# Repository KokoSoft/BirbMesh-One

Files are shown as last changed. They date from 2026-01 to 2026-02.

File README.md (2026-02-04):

# BirbMesh-One :bird:

The goal of **Birb**s **Mesh**tastic **One** Watt node project was to create an inexpensive and as small as possible Meshtastic node equipped with a 1 W radio module. An important aspect, from my perspective, is ensuring favorable operating conditions for the battery to extend its lifespan. The project supports multiple configuration variants, and the final functionality depends on the components you choose to solder. The core of the design is the energy‑efficient *nRF52840* controller mounted on a ProMicro board. The project is pin‑compatible with [xiaoWa_pcb](https://github.com/gargomoma/xiaoWa_pcb) and [FakeTec](https://github.com/gargomoma/fakeTec_pcb), which means no custom firmware is required.

**Key features**:
- Compact PCB: 27 × 47 mm
- Support for radio modules: E22(M), Ra‑01SH‑P, HT‑RA62
- Optional LCD and user button support
- Optional battery charging control (hardware or software)
- Optional battery voltage monitoring

## Project Description

The project was inspired by the [ikona nano](https://github.com/ndoo/ikoka-nano-meshtastic-device) and [xiaoWa_pcb](https://github.com/gargomoma/xiaoWa_pcb). The former is based on the Seeed Studio XIAO BLE, which is significantly more expensive than the ProMicro and offers fewer available GPIO pins. Additionally, the board is large and includes connectors for the battery and solar panel, which I found unnecessary. A notable strength is the correct implementation of the power supply for the boost converter that generates the supply voltage for the radio module. Another benefit, in my opinion, is the integration of the converter directly on the PCB, which allows it to be controlled programmatically. This makes it possible to switch it off to save energy. It is a project worth recommending, and using the XIAO BLE may be a good choice for those who prefer not to rely on low‑quality ProMicro boards.

Initially, this project was created as an attempt to solve the power‑supply issue present in xiaoWa_pcb, which requires a connected battery for proper operation. The boost converter powering the radio module draws energy directly from the battery connector. Without a battery, the system is powered solely by the *TP4054* charger IC, which has current limiting and built‑in protections. Although the charging current is configurable, it may be reduced to 1/10 of the set value under certain conditions, making it impossible to use the board with external power only. Using the inexpensive *HW‑085* boost converter module is an interesting idea and certainly simplifies building the device. Unfortunately, it cannot be switched off to save power.

<details>
<summary>Notes from the TP4054 datasheet</summary>

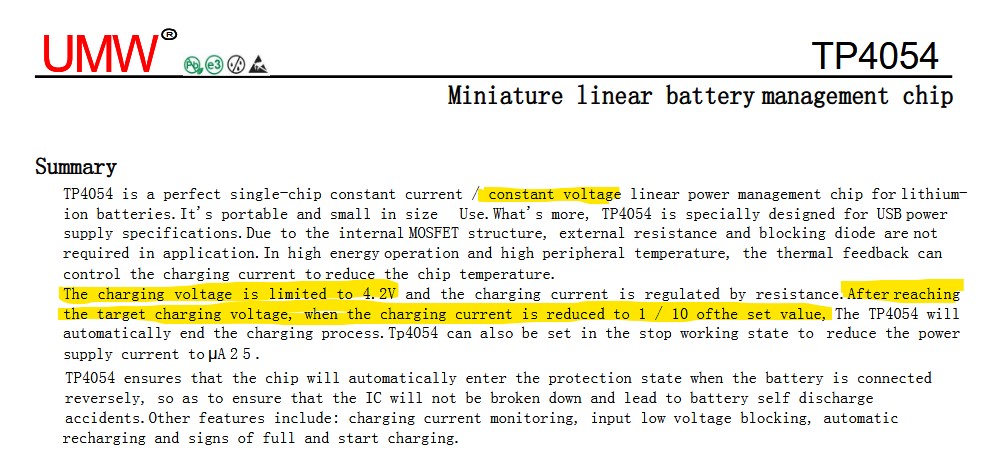
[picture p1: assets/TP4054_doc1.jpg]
TP4054 summary


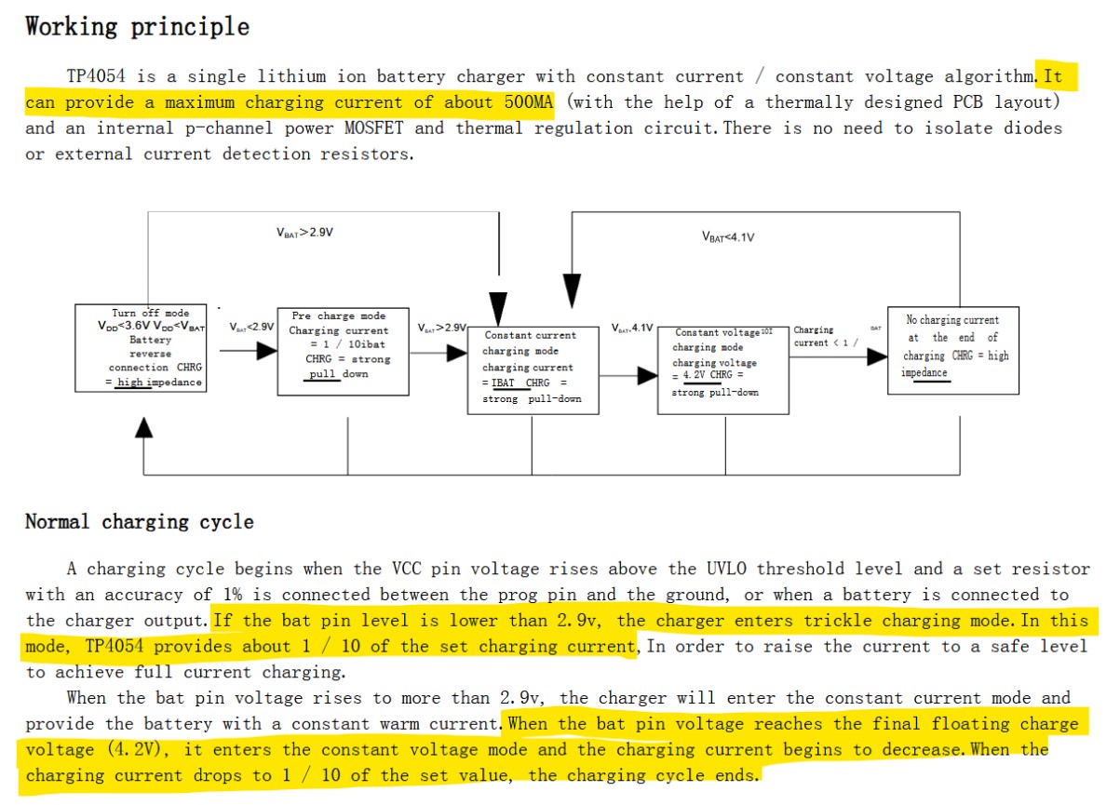
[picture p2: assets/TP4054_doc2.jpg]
TP4054 working principle


</details>

### Power Supply

There are three possible ways to power the radio module:

#### 1. Power from the ProMicro

To properly power the radio module and minimize energy loss, power must be taken from the switching circuit that selects power between USB voltage (*VBUS*) and battery voltage (*VBAT*). On the schematic, this point is labeled **VDDH**. This ensures that neither the battery nor the charger IC is loaded when device is powered from USB. You must route wire from the indicated point on the ProMicro board to the VDDH pad.

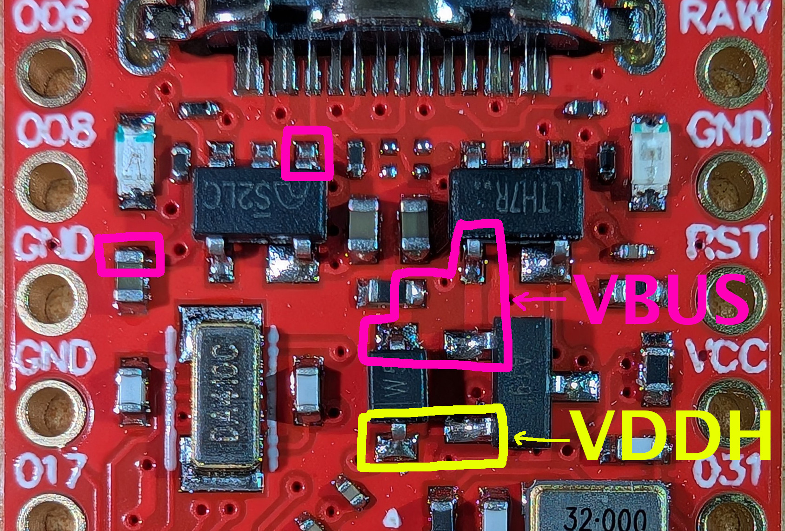
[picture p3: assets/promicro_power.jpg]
ProMicro power pads

<sub>Image created using a photo from the [nrf52840‑promicro](https://github.com/sasodoma/nrf52840-promicro) repository by [sasodoma](https://github.com/sasodoma).

Optionally, if you want to supply 5 V externally (through connector `J1`) without using USB socket, connect the VBUS pad as well.

#### 2. Independent power‑switching circuit

If you prefer not to draw high current through the questionable‑quality components on the ProMicro, you can build your own voltage‑switching circuit. To do this, solder components `Q1` and `D1`. You must also connect the VBUS pad to allow powering the radio from USB.

#### 3. Compatibility mode with xiaoWa_pcb

If you want to minimize soldering and always use the device with battery connected, you can use this compatibility mode. Short the `JP1` jumper on the bottom of the PCB. The radio will be powered directly from the battery, which will load the charger IC too.

### Boost Converter

High‑power radio modules require a 5 V supply to operate at full output power. This voltage is provided by a boost converter. If you are ordering an assembled board or are comfortable with soldering, the best solution is to build the converter using the *MT3608* IC. Populate components `L1`, `U4`, `D3`, `R11`, `R12`, `C7`, and `C9`.

Alternatively, to avoid soldering small components, you may use the *HW‑085* boost module. In its default configuration, it cannot be disabled to reduce power consumption. However, the project allows adding power control: cut jumper `JP7` (shorted by default) and solder `Q3`, `Q4`, and `R13`.

> [!NOTE]
> If you plan to use a radio module that does not require 5 V (e.g., *HT‑RA62*) or do not need full transmit power, you may omit the boost converter.

### Radio Module

Based on my experience with Meshtastic networks, using an 868 MHz SAW filter significantly improves reception quality, though they have low power tolerance. Cavity filters, on the other hand, are large and expensive. In Europe, the *E22P‑868M30S* module appears to be an ideal solution, offering a built‑in receive‑path filter and high transmit power.

#### E22 / E22P Module

The module supports a wide supply range of 3.3 -- 5 V. Full transmit power requires ≥5 V, so a boost converter is necessary. If full power is not required, you may omit the converter and short *VIN* to *VOUT*. The supply voltage will then equal the battery voltage or approximately 4.7 V when externally powered.

The *T/R CTRL* (*RXEN*) pin is controlled by *SX126x* *DIO2*. The *EN* (*TXEN*) pin is controlled by nRF `P0.17`.

#### Ra‑01SH‑P Module

This module is a cheaper alternative to the E22 series, offering 29/31 dBm output power. However, **it does not include a TCXO**. To achieve full power, 5 V must be supplied to the *VCCPA* pin, requiring a boost converter and shorting pads 1–2 on `JP6`.

> [!IMPORTANT]
> The modules documentation states: _"In the default BOM configuration of the Ra‑01SH‑P module, PA is powered by the 3V3 pin of the module, and the VCCPA pin can be left floating."_

#### HT‑RA62 Module

This module is powered from the ProMicro **EXTVCC** 3.3 V rail. No boost converter is required. Short pads 2–3 on `JP6` to connect *DIO2* to *TXEN*.

### Battery Voltage Monitoring (optional)

The monitoring circuit uses two comparators with hysteresis. U1 (*MIC841H*) asserts reset when battery voltage drops below 3.6 V (\~20% charge). Reset is released above 3.7 V (\~30%).

`U2` limits the maximum charge level. When voltage exceeds 4.05 V (\~80%), the `PROG` pin of the *TP4054* charger is disconnected.

To enable charge control, remove the charging‑current‑setting resistor from the ProMicro.
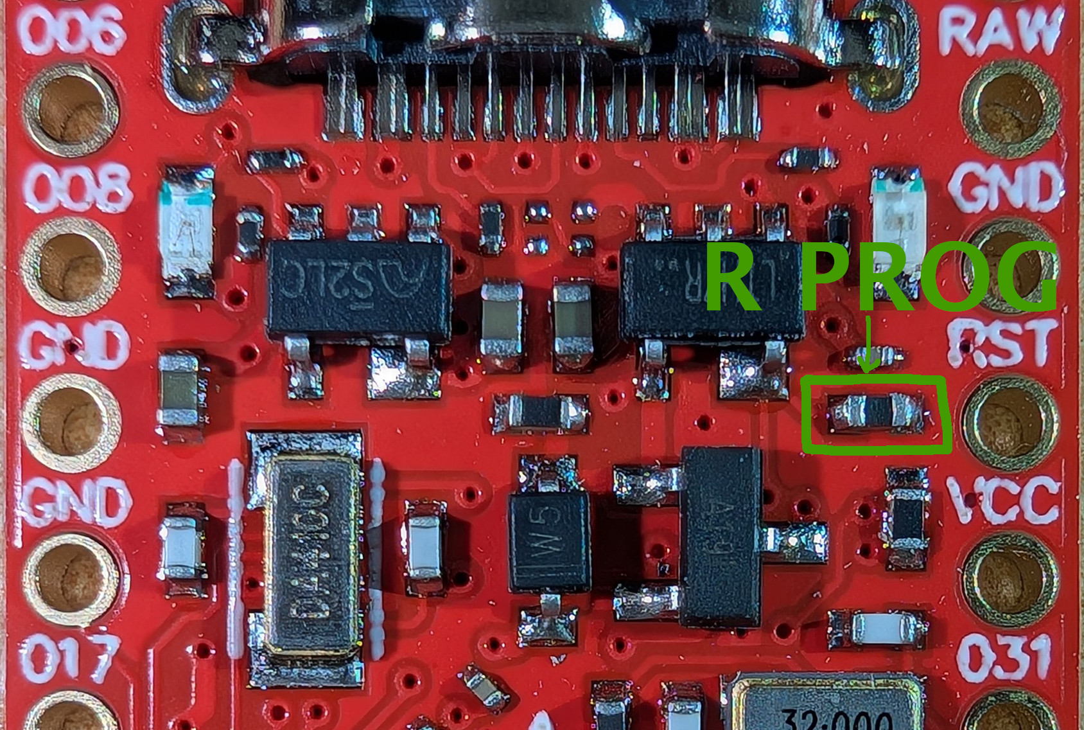
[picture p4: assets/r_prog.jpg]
Charging‑current‑setting resistor on ProMicro

<sub>Image created using a photo from the [nrf52840‑promicro](https://github.com/sasodoma/nrf52840-promicro) repository by [sasodoma](https://github.com/sasodoma).

Charging current is set by resistor `R8`.

Comparator thresholds are configured using the resistor divider `R2–R5`. Capacitor `C1` filters voltage fluctuations during radio transmission to prevent unwanted resets.

If you do not want hardware‑level reset and charge control but still want battery‑level monitoring in software, install only `R1` and `R2`.

#### Charge Control

To control charging from firmware:

- Remove the charging‑current‑setting resistor from the ProMicro.
- Install `R8` to set the desired charging current.
- Short `JP5` or install `Q2`.

## Ordering the PCBs
## Preparing firmware
## Soldering

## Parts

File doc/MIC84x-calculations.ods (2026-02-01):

Voltage calculations:
R1 | 1966 | VREF | 1,24 | V | Internal reference voltage
R2 | 28 | VIN(LO) | 3,599961278 | V | Power off
R3 | 87 | VIN(HI) | 3,700258706 | V | Power on
R4 | 918 | VIN2(LO) | 4,050936819 | V | Disable charger
S | 2999
Resistors calulation:
R1 | 1966,666667
R2 | 27,92792793 | VIN(LO) | 3,6 | V | Power off
R3 | 86,88688689 | VIN(HI) | 3,7 | V | Power on
R4 | 918,5185185 | VIN2(LO) | 4,05 | V | Disable charger
Target: | 3000

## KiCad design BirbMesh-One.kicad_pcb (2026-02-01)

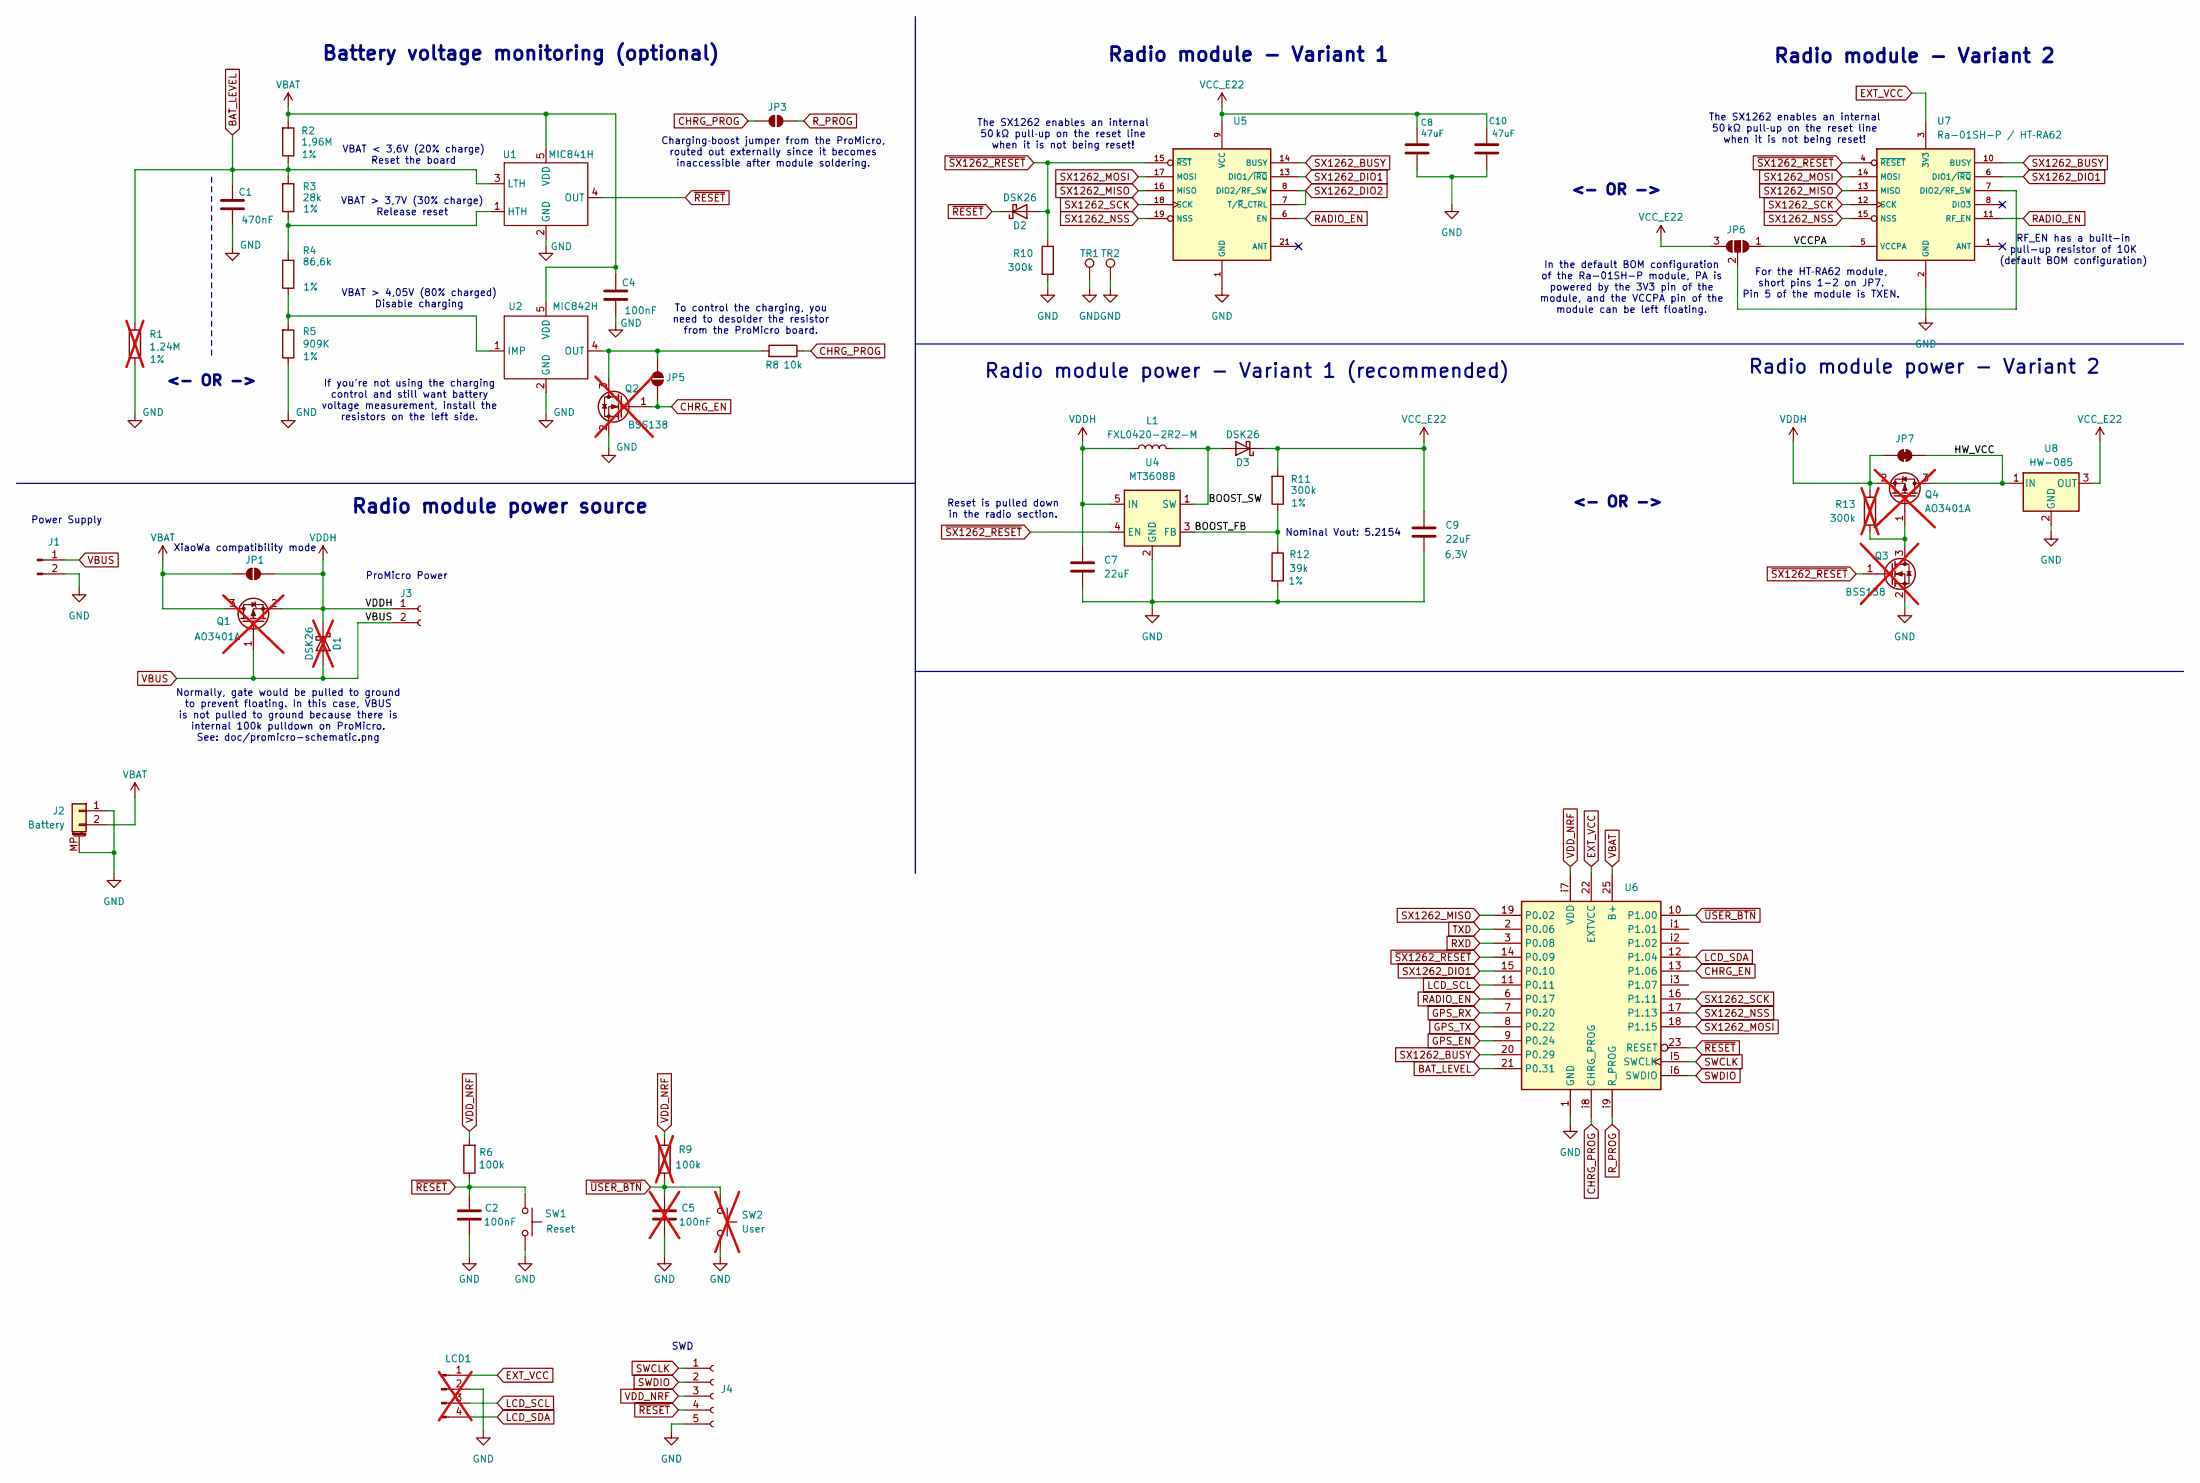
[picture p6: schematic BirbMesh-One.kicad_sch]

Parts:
C1: 470nF; C_0603_1608Metric_Pad1.08x0.95mm_HandSolder; Voltage 6,3V
C2: 100nF; C_0603_1608Metric_Pad1.08x0.95mm_HandSolder
C4: 100nF; C_0603_1608Metric_Pad1.08x0.95mm_HandSolder; Voltage 6,3V
C5: 100nF; C_0603_1608Metric_Pad1.08x0.95mm_HandSolder; not fitted
C7: 22uF; C_0603_1608Metric_Pad1.08x0.95mm_HandSolder; MPN CL10A226MQ8NRNC; LCSC C59461
C8, C10: 47uF; C_0805_2012Metric_Pad1.18x1.45mm_HandSolder; MPN CL31A107MQHNNNE; LCSC C15008
C9: 22uF; C_0603_1608Metric_Pad1.08x0.95mm_HandSolder; Voltage 6,3V; MPN CL10A226MQ8NRNC; LCSC C59461
D1: DSK26; D_SOD-123F; LCSC C7502712; not fitted
D2, D3: DSK26; D_SOD-123F; LCSC C7502712
J1: Conn_01x04_Pin; PinHeader_1x02_P2.54mm_Vertical
J2: Battery; JST_PH_S2B-PH-SM4-TB_1x02-1MP_P2.00mm_Horizontal
J3: Conn_01x02_Socket; PinHeader_1x02_P2.54mm_Vertical
J4: Conn_01x05_Socket; PinHeader_1x05_P1.27mm_Vertical
JP1, JP3, JP5: SolderJumper_2_Open; SolderJumper-2_P1.3mm_Open_TrianglePad1.0x1.5mm
JP6: SolderJumper_3_Open; SolderJumper-3_P1.3mm_Open_RoundedPad1.0x1.5mm
JP7: SolderJumper_2_Bridged; SolderJumper-2_P1.3mm_Bridged_Pad1.0x1.5mm
L1: FXL0420-2R2-M; L_Changjiang_FXL0420; MPN SMMS0650-220M; LCSC C167860
LCD1: Conn_01x04_Pin; PinHeader_1x04_P2.54mm_Vertical; not fitted
Q1, Q4: AO3401A; SOT-23; LCSC C15127; not fitted
Q2, Q3: BSS138; SOT-23; not fitted
R1: 1,24M; R_0603_1608Metric_Pad0.98x0.95mm_HandSolder; Tolerance 1%; not fitted
R2: 1,96M; R_0603_1608Metric_Pad0.98x0.95mm_HandSolder; Tolerance 1%
R3: 28k; R_0603_1608Metric_Pad0.98x0.95mm_HandSolder; Tolerance 1%
R4: 86,6k; R_0603_1608Metric_Pad0.98x0.95mm_HandSolder; Tolerance 1%
R5: 909K; R_0603_1608Metric_Pad0.98x0.95mm_HandSolder; Tolerance 1%
R6: 100k; R_0603_1608Metric_Pad0.98x0.95mm_HandSolder
R8: 10k; R_0603_1608Metric_Pad0.98x0.95mm_HandSolder
R9: 100k; R_0603_1608Metric_Pad0.98x0.95mm_HandSolder; not fitted
R10: 300k; R_0603_1608Metric_Pad0.98x0.95mm_HandSolder; MPN 0603WAF1502T5E
R11: 300k; R_0603_1608Metric_Pad0.98x0.95mm_HandSolder; Tolerance 1%
R12: 39k; R_0603_1608Metric_Pad0.98x0.95mm_HandSolder; Tolerance 1%; LCSC C22843
R13: 300k; R_0603_1608Metric_Pad0.98x0.95mm_HandSolder; MPN 0603WAF1502T5E; not fitted
SW1: Reset; SW_Push_SPST_NO_Alps_SKRK
SW2: User; SW_Push_SPST_NO_Alps_SKRK; LCSC C318884; not fitted
TR1, TR2: PTH; PinSocket_1x01_P2.54mm_Vertical
U1: MIC841H; SOT-353_SC-70-5
U2: MIC842H; SOT-353_SC-70-5
U4: MT3608B; SOT-23-6; LCSC C2932326
U5: E22P-868M30S
U6: ProMicro-all-pins_smd
U7: Ra-01SH-P / HT‑RA62; Ra-01SH-P
U8: HW-085

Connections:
/BOOST_FB: R11.1, R12.1, U4.3 (FB)
/BOOST_SW: D3.2 (A), L1.2, U4.1 (SW)
/HW_VCC: JP7.2 (B), Q4.3 (D), U8.1 (IN)
/VCCPA: JP6.1 (A), U7.5 (VCCPA)
BAT_LEVEL: C1.1, R1.2, R2.1, R3.2, U1.3 (LTH), U6.21 (P0.31)
CHRG_EN: JP5.1 (A), Q2.1 (G), U6.13 (P1.06)
CHRG_PROG: JP3.1 (A), R8.1, U6.i8 (CHRG_PROG)
EXT_VCC: LCD1.1, U6.22 (EXTVCC), U7.3 (3V3)
GND: C1.2, C2.1, C4.2, C5.1, C7.2, C8.1, C9.2, C10.1, J1.2, J2.1, J2.MP (MountPin), J4.5, LCD1.2, Q2.2 (S), Q3.2 (S), R1.1, R5.1, R10.2, R12.2, SW1.1, SW2.2, TR1.1, TR2.1, U1.2 (GND), U2.2 (GND), U4.2 (GND), U5.1 (GND), U6.1 (GND), U7.2 (GND), U8.2 (GND)
GPS_EN: U6.9 (P0.24)
GPS_RX: U6.7 (P0.20)
GPS_TX: U6.8 (P0.22)
LCD_SCL: LCD1.3, U6.11 (P0.11)
LCD_SDA: LCD1.4, U6.12 (P1.04)
unnamed: JP5.2 (B), Q2.3 (D), R8.2, U2.4 (OUT)
unnamed: JP6.2 (C), U7.7 (DIO2/RF_SW)
unnamed: Q3.3 (D), Q4.1 (G), R13.2
unnamed: R3.1, R4.2, U1.1 (HTH)
unnamed: R4.1, R5.2, U2.1 (IMP)
RADIO_EN: U5.6 (EN), U6.6 (P0.17), U7.11 (RF_EN)
RXD: U6.3 (P0.08)
R_PROG: JP3.2 (B), U6.i9 (R_PROG)
SWCLK: J4.1, U6.i5 (SWCLK)
SWDIO: J4.2, U6.i6 (SWDIO)
SX1262_BUSY: U5.14 (BUSY), U6.20 (P0.29), U7.10 (BUSY)
SX1262_DIO1: U5.13 (DIO1/~IRQ), U6.15 (P0.10), U7.6 (DIO1/~IRQ)
SX1262_DIO2: U5.7 (T/~R_CTRL), U5.8 (DIO2/RF_SW)
SX1262_MISO: U5.16 (MISO), U6.19 (P0.02), U7.13 (MISO)
SX1262_MOSI: U5.17 (MOSI), U6.18 (P1.15), U7.14 (MOSI)
SX1262_NSS: U5.19 (NSS), U6.17 (P1.13), U7.15 (NSS)
SX1262_SCK: U5.18 (SCK), U6.16 (P1.11), U7.12 (SCK)
TXD: U6.2 (P0.06)
VBAT: C4.1, J2.2, JP1.1 (A), Q1.3 (D), R2.2, U1.5 (VDD), U2.5 (VDD), U6.25 (B+)
VBUS: D1.2 (A), J1.1, J3.2, Q1.1 (G)
VCC_E22: C8.2, C9.1, C10.2, D3.1 (K), JP6.3 (B), R11.2, U5.9 (VCC), U8.3 (OUT)
VDDH: C7.1, D1.1 (K), J3.1, JP1.2 (B), JP7.1 (A), L1.1, Q1.2 (S), Q4.2 (S), R13.1, U4.5 (IN)
VDD_NRF: J4.3, R6.2, R9.2, U6.i7 (VDD)
~RESET: C2.2, D2.1 (K), J4.4, R6.1, SW1.2, U1.4 (OUT), U6.23 (RESET)
~SX1262_RESET: D2.2 (A), Q3.1 (G), R10.1, U4.4 (EN), U5.15 (~RST), U6.14 (P0.09), U7.4 (~RESET)
~USER_BTN: C5.2, R9.1, SW2.1, U6.10 (P1.00)

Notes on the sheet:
Radio module - Variant 2
For the HT‑RA62 module, short pins 1-2 on JP7. Pin 5 of the module is TXEN.
To control the charging, you need to desolder the resistor from the ProMicro board.
The SX1262 enables an internal 50 kΩ pull‑up on the reset line when it is not being reset!
SWD
VBAT > 4,05V (80% charged) Disable charging
Radio module power - Variant 1 (recommended)
Radio module - Variant 1
<- OR ->
VBAT > 3,7V (30% charge) Release reset
Radio module power source
Battery voltage monitoring (optional)
Radio module power - Variant 2
XiaoWa compatibility mode
Power Supply
Normally, gate would be pulled to ground to prevent floating. In this case, VBUS is not pulled to ground because there is internal 100k pulldown on ProMicro. See: doc/promicro-schematic.png
Charging‑boost jumper from the ProMicro, routed out externally since it becomes inaccessible after module soldering.
Reset is pulled down in the radio section.
ProMicro Power
In the default BOM configuration of the Ra-01SH-P module, PA is powered by the 3V3 pin of the module, and the VCCPA pin of the module can be left floating.
VBAT < 3,6V (20% charge) Reset the board
Nominal Vout: 5.2154
RF_EN has a built-in pull-up resistor of 10K (default BOM configuration)
If you're not using the charging control and still want battery voltage measurement, install the resistors on the left side.

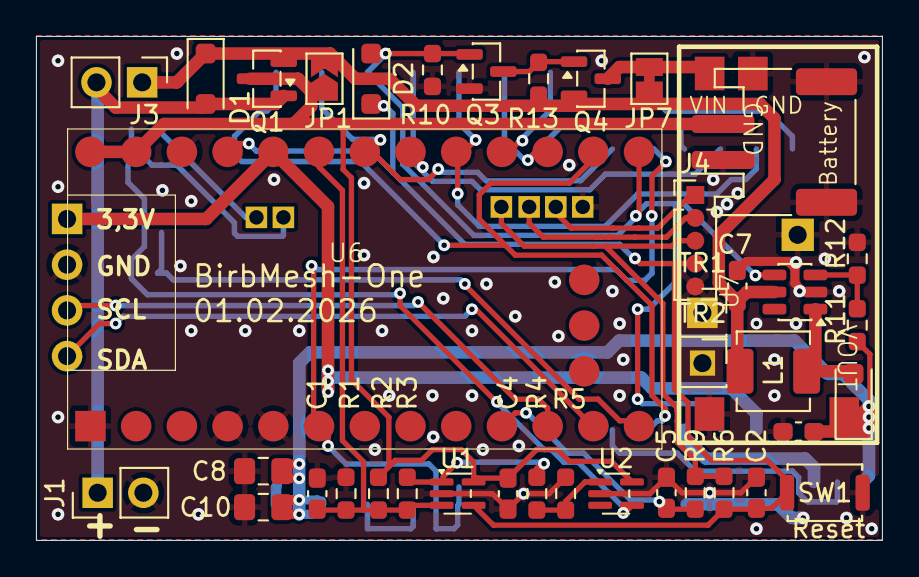
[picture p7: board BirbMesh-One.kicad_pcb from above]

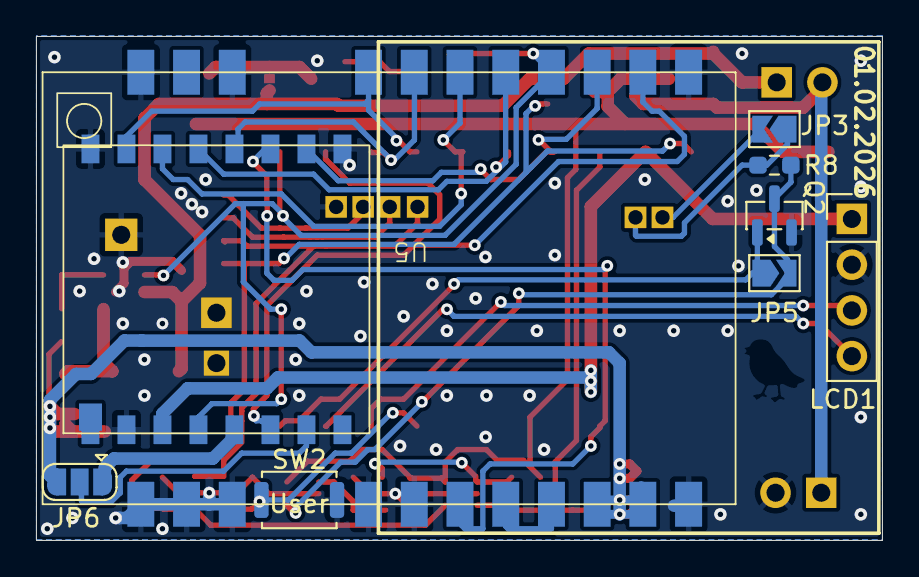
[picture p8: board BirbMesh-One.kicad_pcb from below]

Board: 2 copper layers, 47.0 x 28.0 mm, 49 parts (9 on the bottom side), 35 nets.

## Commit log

2026-01-21 doc: Add datasheet for nRF52, E22 and ProMicro schematic
    Add full dump of available download files for E22P-868M30S module.
    Add datasheet for nRF52840.
    Add schematic for chinese ProMicro.
2026-02-01 symbols: footprints: Add symbols for ProMicro and HW-085
    Add symbol and footprints for ProMicro board.
    Add footprint for HW-085.
2026-02-01 symbols: Add symbol and footprint for E22P-868M30S
    The E22P-xxxM30S series module is a surface-mount LoRa™ wireless module
    independently developed based on the Semtech high-performance RF chip
    SX126x. It has a maximum power of 30dBm and is suitable for the
    433/868/915 MHz frequency band. It uses an industrial-grade
    high-precision active temperature-compensated crystal oscillator
    internally.
2026-02-01 symbols: Add symbol for MIC841 and MIC842
    The MIT841 is a comparator with 1.25% Reference and Adjustable
    Hysteresis. The device is intended for voltage monitoring applications.
    External resistors are used to set the voltage monitor threshold. When
    the threshold is crossed, the outputs switch polarity.
    The MIC842 incorporates a voltage reference and comparator with fixed
    internal hysteresis.
2026-02-01 symbols: Add symbol and footprint for Ra-01SH-P
    Ra-01SH-P is a LoRa series module designed and developed by Shenzhen
    Ai-Thinker Technology Co., Ltd.
2026-02-01 symbols: Add E22 thermal footprint
    The E22P-868M30S radio module has a grid of thermal pads on the
    underside, which are not included in the documentation or the official
    footprint. Add a new E22P-868M30S-thermal footprint that includes the
    thermal pads.
2026-02-01 sch: pcb: BirbMesh-One Alpha
    First version of the schematic and printed circuit board project.
    [BirbMesh-One.kicad_pcb, BirbMesh-One.kicad_sch]
2026-02-01 doc: Add datasheet for MIC841 and MIC842
    Add datasheet for MIT841/MIT842 comparator with 1.25% Reference and
    Adjustable Hysteresis.
    Add a spreadsheet that allows calculating the resistor values for the
    resistive voltage divider used in the project for the battery voltage
    monitor.
    [MIC84x-calculations.ods]
2026-02-01 doc: Add datasheets for components used on the Pro Micro board
    Add datasheets for the TP4054 Li‑Po charger and the ME6217 LDO used on
    the ProMicro board.
2026-02-01 doc: Add datasheet for MT3608
    The MT3608 is a constant frequency, 6-pin SOT23 current mode step-up
    converter intended for small, low power applications. The MT3608
    switches at 1.2MHz and allows the use of tiny, low cost capacitors and
    inductors 2mm or less in height. Internal soft-start results in small
    inrush current and extends battery life.
